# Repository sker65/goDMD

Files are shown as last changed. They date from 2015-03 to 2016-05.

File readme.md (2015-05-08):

# goDMD

Firmware for den pinguino micro zum bau einer goDmd Uhr.

Blog mit Anleitungen und vielen weiter führenden Hinweisen auf http://go-dmd.de/

# Setup der IDE

Als IDE kann Eclipse IDE genutzt werden. Siehe http://cogito-ergo-blog.de/blog/2015/02/25/eclipse-cdt-zur-pic-pic32-entwicklung-nutzen/

# Setup der Umgebung

Dieses Projekt nutzt einen chipKit core und einige Bibliotheken daraus. Um einen passende Core als libCore_api.a zum Linken zu haben, 
empfielt es sich dafür ebenfalls ein Eclipse CDT Projekt zu machen.
Auf dieses Projekt kann dann verwiesen werden.

## Libraries

Die Libraries die genutzt werden sind direkt aus dem Eclipse Workspace heraus verlinkt und 
zeigen auf die UECIDE Installation im home verzeichnis, wo der chipKit core Quellcode abgelegt ist.
Hier sind ggf. die Pfade in den Eclipse-Links anzupassen.

## IRremote Library
Die IR Remote Library wurde für den _Empfang_ an die PIC Umgebung angepasst und das Recorden
des IR Eingangs im Interrput angepasst.

Was nicht geht ist das Senden von IR Command. Die betreffen Stellen, die die PWM Signale 
erzeugen müssen noch von Arduino nach PIC portiert werden.

# SD Library
Diese Library ist eine projekt lokale Kopie der Lib aus dem ChipKIT core mit kleineren 
Anpassungen, damit sie aus dem pinguino micro ohne Probleme läuft.

Änderungen:
SD:
- seekCur eingefügt.

Sd2Card:
- setTranfersize to 8 bit
- setSpeed to 10000000UL (instead of 20000000UL) faster speed does not work

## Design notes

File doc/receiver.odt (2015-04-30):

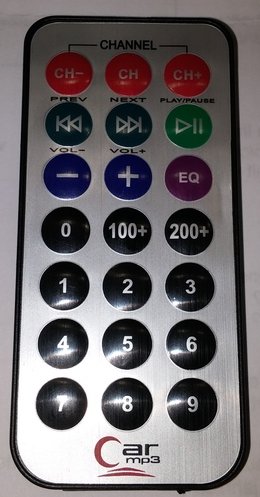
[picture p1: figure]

# Codes für die Fernbedienung der goDMD

Beschreibung | Code
CH- (rot) | 0xe318261b
CH (rot) | 0x00511dbb
CH+ (rot) | 0xee886d7f
Prev (grün) | 0x52a3d41f
Next (grün) | 0xd7e84b1b
Play (grün) | 0x20fe4dbb
- (blau) | 0xf076c13b
+ (blau) | 0xa3c8eddb
EQ (lila) | 0xe5cfbd7f
0 | 0xc101e57b
100+ | 0x97483bfb
200+ | 0xf0c41643
1 | 0x9716be3f
2 | 0x3d9ae3f7
3 | 0x6182021b
4 | 0x8c22657b
5 | 0x488f3cbb
6 | 0x0449e79f
7 | 0x32c6fdf7
8 | 0x1bc0157b
9 | 0x3ec3fc1b

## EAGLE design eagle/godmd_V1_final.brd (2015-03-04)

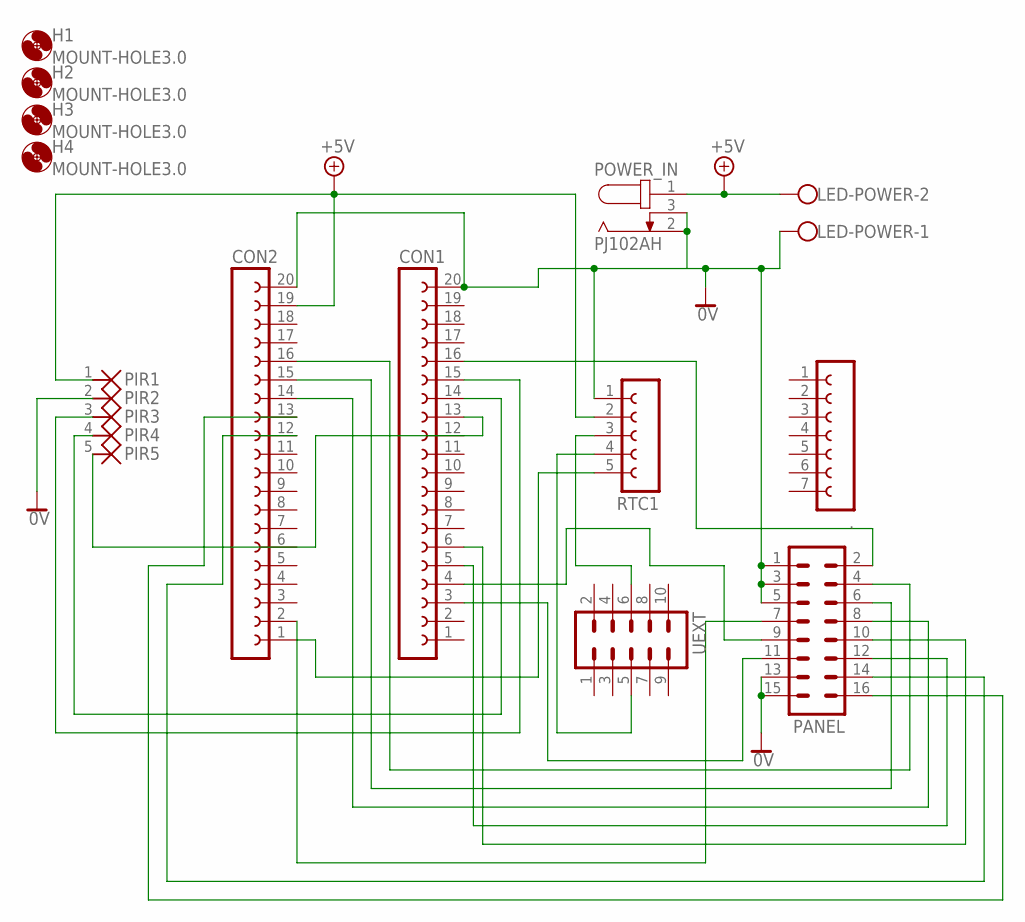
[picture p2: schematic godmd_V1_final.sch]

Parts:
.: FE07-1; FE07
CON1, CON2: FE20-1; FE20
H1, H2, H3, H4: MOUNT-HOLE3.0; 3,0
LED-POWER: W237-102
PANEL: MA08-2
PIR: PS25_5
POWER_IN: PJ102AH; PJ102
RTC1: FE05-1
UEXT: ML10

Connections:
0V: CON1.20, CON2.20, LED-POWER.1, PANEL.1, PANEL.3, PANEL.5, PANEL.13, PANEL.15, PIR.2, POWER_IN.2 (1), POWER_IN.3 (2), RTC1.1
+5V: CON2.19, LED-POWER.2, PIR.1, POWER_IN.1 (3), RTC1.2
A: CON1.16, PANEL.2
B: CON2.16, PANEL.4
C: CON2.15, PANEL.6
CLK: CON2.13, PANEL.16
D: CON2.14, PANEL.8
GD1: CON1.6, PANEL.10
GD2: CON1.5, PANEL.12
IRREC: CON1.14, PIR.4
LAT: CON2.12, PANEL.14
unnamed: RTC1.3, UEXT.6
unnamed: RTC1.4, UEXT.5
unnamed: CON2.1, RTC1.5
unnamed: CON2.2, PANEL.7
PIR-AUX: CON1.13, PIR.5
PIRDATA: CON1.15, PIR.3
RD1: CON1.4, PANEL.9
RD2: CON1.3, PANEL.11

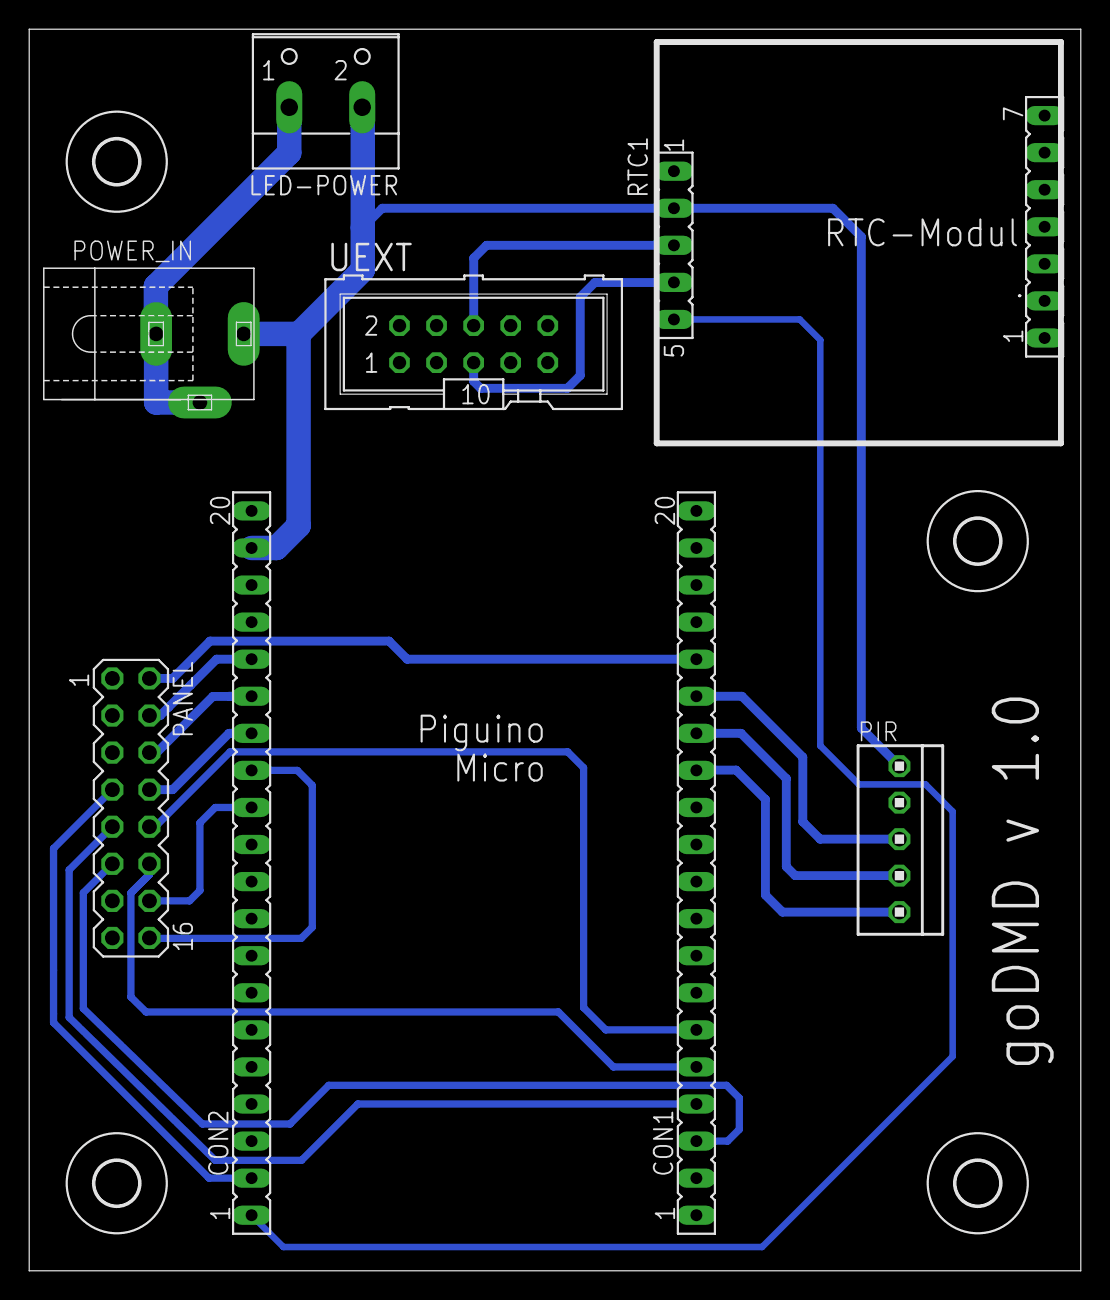
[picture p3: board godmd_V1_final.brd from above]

Board: 2 copper layers, 72.1 x 85.1 mm, 13 parts (0 on the bottom side), 19 nets.

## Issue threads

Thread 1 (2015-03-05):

farbwechsel in main loop

sker65, 2015-03-05:
Das Menü bietet einen Farbwechsel für Animation und Uhr an. Ist aber noch nicht implementiert

sker65, 2015-05-08:
ist nun verfügbar der Wechsel ist zufällig alle 60 sec

Closed 2015-05-08.

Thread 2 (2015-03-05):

helligkeits regelung LED

sker65, 2015-03-05:
Overall helligkeits steuerung ist noch nicht implementiert
an ende des interrupts, müssen die LED aus bleiben für einen Anteil der
Zeit die eigentlich gesetzt ist und zwar jedes zweite mal.

sker65, 2015-05-08:
einfach mit den Abtastzeiten realisiert

Closed 2015-05-08.

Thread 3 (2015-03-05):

kleiner Font für Uhr unterstützen

sker65, 2015-03-05:
die Uhr soll bei laufender Animation auch mit alternativem kleinen Font gezeigt werden.

Font wird bereits geladen, aber anzeige geht noch nicht.

sker65, 2015-03-06:
beim Anzeigen des kleinen Fonts muss darauf geachtet werden, dass die Bits passend zum yoffset verschachtelt werden. Evtl. ist es besser den kleinen Font daher nicht schon vorher zur transformieren

sker65, 2015-03-10:
umstellung auf regular bit planes, kleiner font geht

Closed 2015-03-11.

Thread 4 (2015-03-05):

EEPROM mit SDCard simulieren

sker65, 2015-03-05:
da der PIC kein EEPROM hat und das flashen nicht korrekt funktioniert, soll einfach ein SD File geschrieben werden was die Einstellungen speichert.

Ist implementiert, funktioniert aber irgendwie nicht korrekt

sker65, 2015-03-05:
funktioniert jetzt

Closed 2015-03-05.

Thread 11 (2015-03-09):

FSK Tag supporten

sker65, 2015-03-09:
geschrieben / gelesen wird das im file format bereits, aber noch nicht danach gefiltert.
Um filtern zu können, muss noch eine Einstellung ins Menü mit der man die Altersgrenze festlegt

sker65, 2015-03-11:
Menü Eintrag ist da, Filter klappt

Closed 2015-03-11.

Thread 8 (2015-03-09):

Zwischen den Sync-Punkte zur RTC geht die Uhr nach

sker65, 2015-03-09:
Zwischen den Sync-Punkte zur RTC geht die Uhr nach. Passt irgendwie nicht

sker65, 2015-03-16:
sollte weg sein, jetzt wird als aktuelle bezugspunkt immer millis() gerufen

sker65, 2015-05-02:
das zählen der millis ist tatsächlich ungenau, wegen der vielen Zeit die die CPU im Interrupt verbringt.
Lösung bislang: es wird öfter mit der RTC sychronisiert

Closed 2015-05-02.

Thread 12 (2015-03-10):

Ablauf der DMD Animation mit zufälliger Reihenfolge

sker65, 2015-03-10:
Um den Ablauf zufällig zu machen, sollte das File einmal komplett indiziert sein, d.h. der Anfang der Animation muss bekannt sein.

Entweder der Compiler erzeugt so ein Verzeichnis oder es wird zur Laufzeit aufgebaut.

sker65, 2015-03-16:
done

Closed 2015-03-16.

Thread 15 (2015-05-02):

grosse Schrift geht nicht mit Maske (oben drüber)

sker65, 2015-05-02:
wird aktuell nicht genutzt. sollte umgestellt werden, in der Form, dass die die Maske in den Buffer schreibt (Vielleicht ist der Buffer einfach ein weiterer Font)

sker65, 2015-05-08:
da gibts noch effekte, muss ich untersuchen

sker65, 2015-08-02:
fixed in 1.03

Closed 2015-08-02.

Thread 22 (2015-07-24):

Anzeige der Temperatur häufiger

sker65, 2015-07-24:
EInstellbar machen

juergen-schuch, 2015-08-02:
Auch die Anzeigedauer änderbar?

sker65, 2015-08-02:
- fix with 1.02

Closed 2015-08-02.

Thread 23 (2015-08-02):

Clock is not settable

juergen-schuch, 2015-08-02:
Not possible to set the time
after adjust time and date with remote control or the button
the displayed time starts always wit 17:30
Setting for i.e. time display hh:mm / hh:mm:ss works
firmware is newest : goDMD-1.01.hex
date is 29.04.43 although in setting menue the year is correct: 2015

sker65, 2015-08-02:
Possible hardware error. RTC adjusts are written to the rtc modul directly when menu is closed.
in this sense time / date adjusts are different from other options, which are written to file.

Closed 2015-08-02.

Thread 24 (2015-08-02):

Pixel für FB Anzeige per Menü deaktiveren

master-of-chaos, 2015-08-02:
Anscheinend registriert der IR Empfänger auch Signale anderer Fernbedienungen .
Hier wäre es schön, wenn man die Signalisierung des Empfangs durch den linken obersten Pixel per Setting deaktivieren könnte,

sker65, 2015-08-02:
Wird in einem der nächsten Releases supported werden.

sker65, 2015-08-02:
fixed in 1.03

Closed 2015-08-02.

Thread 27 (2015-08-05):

Issues 1.05 - Switch from and to animations buggy

Spyke1975, 2015-08-05:
- before date appears clock is shown shortly
- if date is shown, after finishing animations date is shown shortly before clock appears
- temperature stays dark within animation

sker65, 2015-08-06:
temp -> ani: clock.clear() seems to be missing. Temp is displayed in the back.
insert clock while ani, reset clock mode always to clock, regardless if it was date / temp

Closed 2015-08-13.

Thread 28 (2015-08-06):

Check IR-Codes in 1.05

sker65, 2015-08-06:
After updating ir codes and flashing my personal clock, absolutly no code is recognized any more.

Codes now look completely different, not sure if tested with Ralf remote, are there two different types of remotes?

sker65, 2015-08-07:
there is a dependency to the used hardware ir receiver. prototype board is other than series.

must be checked carfully, when doing a new series

Closed 2015-08-07.

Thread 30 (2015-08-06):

Create a menu to choose a temperatur offset

sker65, 2015-08-06:
As the tempature sensors are not very accurate, it should be possible to add / subtract an offset to the actual measured temperature

sker65, 2015-08-07:
- fixed in 1.06

Closed 2015-08-07.

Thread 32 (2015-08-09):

Handle overflow of millis()

sker65, 2015-08-09:
millis will overflow after 49 day, make sure clock is running well on overflow.

suggestions:
- register / reset all milli storing var in a way that they can be reseted / adjusted
- switch to another time var with 0.1 sec resolution to get a 4900 day overflow period.
-> this can be done by register a timer0 callback in chipkit

Closed 2015-10-05.

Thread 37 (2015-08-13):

Uhr bleibt nach einiger Zeit dunkel

sker65, 2015-08-13:
_From @eliottk on August 8, 2015 10:52_

Meine Uhr hat das Problem, dass sie nachdem sie sich ausgeschalten hat, da sich niemand im Raum befand und zappelte, sich hin und wieder nicht mehr einschaltet. Das ganze geht ein paar mal gut und dann bleibt sie dunkel. Ich muss dann einen Reset machen und dann geht sie wieder.

_Copied from original issue: sker65/go-dmd-clock#8_

sker65, 2015-08-13:
Leider das falsche Projekt

eliottk, 2015-08-15:
Hi,

jetzt kenne ich mich nicht mehr aus, wieso das falsche Projekt? Es geht hier doch um die Probleme mit der GO-DMD Uhr von dir oder?

lg.
Erich

mdillmann, 2015-08-15:
Erich, Du hattest den Bug report im Projekt der Werkzeuge (go-dmd-clock) geöffnet. Das Projekt für die Firmware ist das goDMD.
Stefan hat das rüberkopiert.

Zugegeben, Stefan hat das etwas unglücklich benannt ...

VG,
-Markus

eliottk, 2015-08-16:
Hi,

okay danke.

Folgende Einstellungen habe ich bei meiner Uhr, evt. ist ja ein Software Problem:

FW: 1.05
Helligkeit: 4
Zeit Mode: H:M
Dauer Zeit Anzeige: 5
Dauer Dat Anz: 2
Farbe-Ani: wechsel
Farbe-Uhr: wechsel
Dauer Temp Anz: 4
PIR Mode: switchoff
FSK: 18
Uhr Blink: an
Uhr 12/24: 24
Ani Reihenfolge: zufällig
Schrift: 0
LED Indicator: an
PIR Hold Time: 1

Die Uhr geht nach ca. 21 min. aus und kommt nicht mehr retour. Erst nach eine, reset (Knopf oder Stroemkabel) funktioniert sie wieder für 21 min.

lg.
Erich

sker65, 2015-08-16:
Hi Erich, bitte teste mal ohne den FSK filter. Der war schon mal Ursache
für ein Problem. Ist nur so ein Gefühl, eigentlich sehen die Einstellungen
OK aus.
Gruss Steve

eliottk <notifications@github.com> schrieb am So., 16. Aug. 2015 15:03:

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

eliottk, 2015-08-16:
Hi,

auf was soll das FSK stellen, ich kann da ja nur 6, 12, 18 auswählen. OFF gibt es da nicht.

lg.
Erich

sker65, 2015-08-16:
Na probiere halt mal irgendwas anderes es sind ja nur vier stufen.
Gruss Steve

eliottk <notifications@github.com> schrieb am So., 16. Aug. 2015 16:21:

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

eliottk, 2015-08-17:
Hi,

der Filter war es nicht, es scheint die foo.ani Datei zu sein die den Fehler verursacht. Ich habe heute mal eine neue gemacht mit nur 3-4 Animationen und seither läuft die Uhr.

@sker65
Ich sende dir einen Dorpbox Link per Mail mit der foo.ani mit der sie nicht funktioniert hat. evt. kanst du den Fehler finden.

lg.
Erich

sker65, 2015-08-17:
Ok, gut Erich, dass du den Fehler eingrenzen konntest. Wichtig wäre noch zu wissen, welche Firmware Version du verwendest.

sker65, 2015-08-17:
sorry ich habs grad gesehen, es ist die 1.05

eliottk, 2015-08-17:
Ok, der Link zur der verwendeten foo.ani ist auch raus an dich.

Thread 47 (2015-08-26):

Speed up serial communication with ESP to 112500 baud

sker65, 2015-08-26:
in preparation of file transfer the speed of the comm link to ESP must be faster.

as the esp is not reseted, when pic restarts, we need to sync baud rates, regardless what the uart of the esp is set, like this: try 9600, expect crap or CR/LF, try 112500 expect CR/LF

to not delay boot time, we maybe post pone the whole detection as update task.

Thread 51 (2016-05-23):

frame replacement shows error

sker65, 2016-05-23:
see http://vpuniverse.com/forums/topic/2268-pin2dmd-editor/?p=29321

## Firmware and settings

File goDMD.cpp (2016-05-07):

/*
 * go DMD main.
 *
 *  Created on: 08.02.2015
 *      Author: sr
 *      (c) 2015 by Stefan Rinke
 */

#include <IRremote.h>
#include <OneWire.h>
#include <SD.h>
#include <RTClib.h>
#include <DallasTemperature.h>

#include "NtpCallbackHandler.h"
#include "LEDMatrixPanel.h"
#include "Clock.h"
#include "Animation.h"
#include "Menu.h"
#include "PirHandler.h"
#include "NodeCallbackHandler.h"
#include "debug.h"
#include "version.h"
#include <malloc.h>
#include "macros.h"
#include "utility/TimeUtil.h"
#include "DHT.h"

#define DS18B20_PIN CON2_1

#define CLK CON2_13
#define OE CON2_2
#define LAT CON2_12 // schwarz 
#define A CON1_16 // RB0
#define B CON2_16 // RB1
#define C CON2_15 // RB2
#define D CON2_14 // RB3

#define WIDTH 128
#define HEIGHT 32
#define PLANES 16
#define COLORCHANNELS 2

#define INTERNAL_SD_SELECT 51

#define RECV_PIN CON1_14
#define PIR_PIN CON1_15
#define DHT_PIN CON1_16

DHT dht(DHT_PIN);

LEDMatrixPanel panel( A,B,C,D, CLK, LAT, OE, WIDTH, HEIGHT, PLANES,
		COLORCHANNELS, false);

OneWire oneWire(DS18B20_PIN);          // OneWire Referenz setzen
DallasTemperature sensor(&oneWire);   // DS18B20 initialisieren
RTC_DS1307 rtc;

Clock clock(panel, rtc, &SD, &sensor, &dht);
Animation animation(SD, panel, clock);

// set time zone to 1 as default for germany
NtpCallbackHandler ntpCallbackHandler(&clock, 1);
NodeCallbackHandler nodeCallbackHandler(&panel);

NodeMcu node(&ntpCallbackHandler,&nodeCallbackHandler);

Menu menu(&panel, &clock, &SD, &node);

IRrecv irrecv(RECV_PIN);
decode_results results;

PirHandler pir(PIR_PIN);

long nextPixel = 0;
int x = 0;
int y = 0;
bool on=false;


extern "C" char* sbrk(int incr);
int getFreeRam() {
  char top;
  return &top - reinterpret_cast<char*>(sbrk(0));
}

// define a char out hook for printf
extern "C"
{
  void _mon_putc(char s)
  {
   Serial.write(s);
  }
}

void waitBut() {
	panel.println("press button");
	while(digitalRead(PIN_BTN1)==LOW);
	while(digitalRead(PIN_BTN1)==HIGH);
}

#include "ir-codes.h"

void selftest() {
	panel.println("SELFTEST");
	panel.println(VERSION);
	waitBut();
	panel.println("PANELTEST");
	int b = 0;
	boolean run = true;
	boolean seenHigh = false;
	int col = 0;
	int br = 3;
	panel.setAnimationColor(col);
	panel.drawRect(0,0,128,32,br++);
	while( run) {
		if( irrecv.decode(&results) ) {
			if( results.value == BUT_7 && b>0 ) {
				b--;
			}
			if( results.value == BUT_8 && b<10 ) {
				b++;
			}
			if( results.value == BUT_9 ) run = false;
			if( results.value == BUT_1 ) {
				DPRINTF("draw col=%d br=%d\n",col,br);
				panel.setAnimationColor(col);
				panel.drawRect(0,0,128,32,br++);
				if( br >= 4) { //  4
					br = 1;
					col++;
					if( col == 3) col = 0;
				}
			}
			panel.setBrightness(b);
			DPRINTF("set Brightness to %d\n",b);
			irrecv.resume();
		}
		if( digitalRead(PIN_BTN1)==HIGH ) seenHigh = true;
		if( seenHigh && digitalRead(PIN_BTN1)==LOW ) run=false;
	}

	// one pager
	run = true;
	seenHigh = false;
	long update = 0;
	uint32_t lastIr = 0;
	panel.clear();
	while(run) {
		uint32_t now = millis();
		// just hand over
		if( Serial.available() ) {
			int in = Serial.read();
			Serial1.write(in);
		}
		if( Serial1.available()) {
			int out = Serial1.read();
			Serial.write(out);
		}
		if( SAVECMP(now, update) ) {
			update = now+1000;
			if( pir.actual() ) panel.writeText("PIR: true   ",0,0,12);
			else panel.writeText("PIR: false  ",0,0,12);
			char buf[16];
			sprintf(buf,"0x%08x",lastIr);
			panel.writeText(buf,0,8,10);
			sensor.requestTemperatures();
			float actTemp = sensor.getTempCByIndex(0);
			sprintf(buf, "%03.1f *C",actTemp);
			panel.writeText(buf,0,16,7);
			DateTime n = rtc.now();
			sprintf(buf,"%02d:%02d:%02d %02d%02d%02d",
					n.hour(),n.minute(),n.second(),
					n.day(),n.month(),n.year()%1000);
			panel.writeText(buf,0,24,15);
		}
		if( irrecv.decode(&results) ) {
			lastIr = results.value;
			DPRINTF("ircode received %04x\n",lastIr);
			irrecv.resume();
			if( results.value == BUT_9 ) run = false;
		}
		if( digitalRead(PIN_BTN1)==HIGH ) seenHigh = true;
		if( seenHigh && digitalRead(PIN_BTN1)==LOW ) run=false;
	}
	run = true;
	seenHigh = false;
	panel.clear();
	node.start();
	node.setEnableBackgroundCmds(false);
	while(run) {
		uint32_t now = millis();
		node.update(now);
		if( SAVECMP(now,update) ) {
			update = now+1000;
			if( node.isNodeMcuDetected()) {
				panel.writeText("wifi ext active",0,0,15);
				char* ip = node.syncRequestIp();
				char buf[16];
				sprintf(buf, "%-16s",ip);
				panel.writeText(buf,0,8,16);
			} else {
				panel.writeText("no wifi ext.",0,0,12);
			}


		}
		if( digitalRead(PIN_BTN1)==HIGH ) seenHigh = true;
		if( seenHigh && digitalRead(PIN_BTN1)==LOW ) run=false;
	}
	panel.println("press but to cont");
	while( true ){
		panel.setAnimationColor(col);
		panel.drawRect(0,0,128,32,br++);
		if( br == 4) { //  4
			br = 1;
			col++;
			if( col == 3) col = 0;
		}
		delay(700);
		if( digitalRead(PIN_BTN1)==FALSE ) break;
	}
	panel.println("press but to cont");
	waitBut();
	//panel test
	panel.println("IR TEST");
	panel.println("press buttons");
	// loop to receive
	if( irrecv.decode(&results) ) {
		char buf[12];
		sprintf(buf,"0x%08x",results.value);
		panel.println(buf);
		irrecv.resume();
	}


}


void setup() {
	Serial.begin(9600);
#ifdef _DxEBUG
	for( int i =0; i<5;i++) {
		DPRINTF("wait %lu \n", millis());
		delay(1000);
	}
#endif
	DPRINTF2("calling panel begin\n");
	panel.begin();

	panel.setAnimationColor(1);
	panel.setTimeColor(1);
	DPRINTF2("\n");

	node.begin();



	// start ir receiver
	irrecv.enableIRIn();

	panel.println(VERSION);

	DPRINTF2("calling wire begin\n");
	panel.println("start wire ..");
	Wire.begin();
	DPRINTF2("calling rtc begin\n");
	panel.println("start rtc ..");
	rtc.begin();
	
	DPRINTF2("calling sd card begin\n");
	panel.println("start sd card ..");

	if( !SD.begin(INTERNAL_SD_SELECT) ){
	pinMode(INTERNAL_SD_SELECT, OUTPUT);
		DPRINTF2("sd card begin failed\n");
		panel.println("sd card failed");
		selftest();
	} else {
		DPRINTF2("sd card begin success\n");
		delay(500);
		panel.println("boot ok!");
		panel.println("(c)2015 by Steve");
	}

	if( !clock.begin() ) {
		panel.println("init clock fail");
		panel.println("font not found");
	}

	if( !animation.begin() ) {
		panel.println("init anis fail");
		panel.println("*.ani not found");
	}

	uint32_t pclock = getPeripheralClock();
	DPRINTF("system running with periphal clock : %ld\n",pclock);

	sensor.begin();
	DPRINTF("sensors found: %d\n",sensor.getDeviceCount());

//	DPRINTF("Running at: %d\n", System.get());

	if(digitalRead(PIN_BTN1)==FALSE) {
		selftest();
	}

	panel.clear();
	panel.clearTime();

	//pinMode(PIN_LED2,OUTPUT);

	//rtc.adjust(DateTime(__DATE__, __TIME__));
}

int clockShowTime = 2000; // millis to show clock
// viewing mode (with date or not)
int dateMode = 0;
int tempMode = 0;

// TODO no global function this way
void reloadConfig() {
	panel.setAnimationColor(menu.getOption(SET_COLOR_ANI));
	panel.setTimeColor(menu.getOption(SET_COLOR_CLOCK));
	panel.setBrightness(menu.getOption(SET_BRIGHTNESS));
	DPRINTF("panel.setBrightness: %d\n", menu.getOption(SET_BRIGHTNESS));

	clock.setMode(menu.getOption(SET_TIME_MODE)==1?Clock::TIMESEC:Clock::TIME);
	DPRINTF("set time mode: %d\n", menu.getOption(SET_TIME_MODE));

	clockShowTime = 1500 * (menu.getOption(SET_TIME_DURATION)+1);
	dateMode = menu.getOption(SET_DATE_MODE);
	tempMode = menu.getOption(SET_TEMP_MODE);
	animation.setFskMode(menu.getOption(FSK_MODE));
	animation.setRandomOrder(menu.getOption(ANIORDER_MODE)==1);
	clock.setHour24(menu.getOption(H2412_MODE)==MODE_24H);
	clock.setBlinkingTick(menu.getOption(BLINK_MODE)==BLINK_ON);
	clock.requestFont(menu.getOption(CURRENT_FONT));
	pir.setDelay((30+15*menu.getOption(PIR_HOLDTIME))*1000);
	animation.setShowName(menu.getOption(DISPLAY_ANINAME)==0);
	clock.setTempOffset(menu.getOption(TEMP_OFFSET)-7);
}

void testScreen() {
	for( int col = 0; col<16; col++) {
		panel.drawRect(col*8,0,8,32,col);
	}
	while(true);
}

// push main loop behaviour to class

// states
enum State { showTime, showDate, showAni, showMenu, freeze,
	pirNobodyThere, showTemp, showHumi
};

void loop() {
	uint32_t now = millis();

	State state = showTime;

	DHT::ReturnCode rc = dht.readDHT();
	bool dhtPresent = ( rc == DHT::DHT_OK );

	//testScreen();

	menu.loadOptions();
	reloadConfig();

	DPRINTF("free ram %d\n", getFreeRam());

	uint32_t ledInterval = 3000;

	uint32_t switchToAni = now + clockShowTime;

	uint32_t nextColorChange = 0;

	int stateCycle = 0;
	int dateTemp = 0;

	int dstCheck = 0;

	/*int next = millis();

	while( true ) {
		long now = millis();
		if( now > next ) {
			next = now + 5000;
			Serial1.println("=node.info()");
		}
		// just hand over
		if( Serial.available() ) {
			int in = Serial.read();
			Serial1.write(in);
		}
		if( Serial1.available()) {
			int out = Serial1.read();
			Serial.write(out);
		}
	}*/

	node.start();

/*	int t = 0;
	while(t++ < 20) {
		long now = millis();
		node.update(now);
		delay(100);
	}
	DPRINTF("ip: %s\n",node.getIp());
	while(t++ < 20) {
		long now = millis();
		node.update(now);
		delay(100);
	}
	Result* r = node.getApList();
	while( r != NULL ) {
		DPRINTF("AP: %s\n", r->line);
		r = r->next;
	}*/
	bool hasNtpRequested = false;
	bool wifipresetRequested = false;

	TimeUtil timeUtil;
	clock.update(millis());
	timeUtil.setUTCtime(clock.getUnixTime());
	bool actDst = timeUtil.isDaylightSaving();
	bool toggleHumi = false;

	while(true) {
		uint32_t now = millis();

		node.update(now);
		if( now > 1000 && node.isNodeMcuDetected() && menu.hasWifiPreset() && wifipresetRequested == false) {
			wifipresetRequested = true;
			DPRINTF("wifi preset ssid: '%s'\n",menu.getPreset_ssid());
			DPRINTF("wifi preset pw: '%s'\n",menu.getPreset_pw());
			node.configAp( menu.getPreset_ssid(), menu.getPreset_pw());
		}

		if( now > 40000 && node.isNodeMcuDetected() && hasNtpRequested==false ) {
			hasNtpRequested = true;
			node.requestNtpSync(now);
		}

		if( Serial.available() ) {
			String ps = Serial.readStringUntil('\n');
			const char* p = ps.c_str();
			DPRINTF("received string: '%s'\n",p);
			// date +SETTIME%s > /dev/ttyACM0
			// SETTIME<seconds since 1970 utc>
			if( strncmp(p,"SETTIME",7)==0) {
				p += 7;
				long unixtime = 0;
				while( *p != 0) {
					unixtime *= 10;
					if( *p >= '0' && *p <= '9') {
						unixtime += *p -'0';
					}
					p++;
				}
				// simple hack to adjust tz CEST +2 hours
				unixtime += 60*60*2;
				DateTime dt(unixtime);
				DPRINTF("setting rtc clock to: %ld \n", unixtime);
				clock.adjust(&dt);
			}
		} // read from serial

		// handle IR receiver
		if( irrecv.decode(&results) ) {
			menu.notifyEvent(results.value);
			irrecv.resume();
		}
		
		// show with blinking led ISR is running
		// cannot be switched on as it interferes with card reader
		if( panel.getISRCalls() > ledInterval ) {
			panel.resetISRCalls();
			on = !on;
			//digitalWrite(PIN_LED2,on);
			ledInterval = on ? 10000:10000;
			//DPRINTF("free ram %d\n", getFreeRam());
		}

		pir.update(now);
		clock.update(now);
		menu.update(now);

		if( menu.isActive() ) {
			clock.off();
			state = showMenu;
		}


		// do an dst check every minute, regardless
		if( SAVECMP(now, dstCheck)) {
			dstCheck = now + 60000;
			uint32_t unixTime = clock.getUnixTime();
			timeUtil.setUTCtime(unixTime);
			bool dstNew = timeUtil.isDaylightSaving();
			if( dstNew != actDst ) {
				// make dst adjust
				if( dstNew ) {
					// switch to summer time
					DPRINTF2("switching to summer time");
					DateTime dt(unixTime + 3600);
					clock.adjust(&dt);
				} else {
					// switch back to winter time
					DPRINTF2("switching to winter time");
					DateTime dt(unixTime - 3600);
					clock.adjust(&dt);
				}
				actDst = dstNew;
			}
		}

		// ani -> time -> ani
		// or ani -> date -> ( ani -> time -> ) 5x

		switch( state ) {
		case showTime:
			clock.on();
			if( SAVECMP( now , switchToAni) ) {
				DPRINTF("free ram %d\n", getFreeRam());
				if(pir.somebodyHere()) {
					state = showAni;
					clock.off();
					panel.setBrightness(menu.getOption(SET_BRIGHTNESS));
				} else {
					switch( menu.getOption(SET_PIR_MODE) ) {
					case PIR_DIM:
						panel.setBrightness(1);
						// run through is intended
					case PIR_INACTIVE:
						state = showAni;
						clock.off();
						break;
					case PIR_NOANI:
						switchToAni = now + clockShowTime;
						// TODO check date show
						// define transitions as methods
						break;
					case PIR_SWITCHOFF:
						clock.off();
						panel.clear();
						state = pirNobodyThere;
						break;
					}
				}
			}
			clock.update(now);
			break;

		case showTemp:
			clock.setMode(Clock::TEMP);
			clock.on();
			if( SAVECMP( now , switchToAni ) ) {
				state = showAni;
				clock.off();
			}
			clock.update(now);
			break;

		case showHumi:
			clock.setMode(Clock::HUMI);
			clock.on();
			if( SAVECMP( now , switchToAni ) ) {
				state = showAni;
				clock.off();
			}
			clock.update(now);
			break;

		case showDate:
			clock.setMode(Clock::DATE);
			clock.on();
			if( SAVECMP( now , switchToAni ) ) {
				state = showAni;
				clock.off();
			}
			clock.update(now);
			break;

		case showAni:
			if( animation.update(now) ) { // true means ani finished

				if( stateCycle++ > 5 ) { // every five times
					stateCycle = 0;
					dateTemp++;
					// check want to show next temp ot date or simply time
					if( tempMode>0 && dateTemp % 3 == 0 ) {
						toggleHumi = ~toggleHumi;
						if( toggleHumi && dhtPresent ) {
							state=showHumi;
						} else {
							state=showTemp;
						}
						switchToAni = now + 3000 + tempMode * 1500;
					} else {
						if( dateMode > 0 ) {
							state = showDate;
							clock.setMode(Clock::DATE);
							switchToAni = now + 3000 + dateMode * 1500;
						}
					}
				} else {
					switchToAni = now + clockShowTime; // millis to show clock
					state = showTime;
					clock.setMode(menu.getOption(SET_TIME_MODE)==1?Clock::TIMESEC:Clock::TIME);
				}

				// check color change
				if( SAVECMP( now , nextColorChange ) ) {
					nextColorChange = now + 60000;
					if( menu.getOption(SET_COLOR_ANI)==COLOR_CHANGE ) {
						panel.setAnimationColor(random(3));
					}
					if( menu.getOption(SET_COLOR_CLOCK)==COLOR_CHANGE ) {
						panel.setTimeColor(random(3));
					}
				}

			}
			break;

		case showMenu:
			if( !menu.isActive()) {
				// menu is finish / clock is set, but reconfige ani / panel
				reloadConfig();
				state = showTime;
			}
			break;

		case pirNobodyThere:
			ledInterval = 6000;
			if( pir.somebodyHere()) {
				ledInterval = 3000;
				switchToAni = now + clockShowTime; // millis to show clock
				state = showTime;
			}
			break;
		case freeze:

			break;
		}
		
	}
}

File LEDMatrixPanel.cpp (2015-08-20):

/*
 * LEDMatrixPanel.cpp
 *
 *  Created on: 29.01.2015
 *      Author: sr
 */

#include "LEDMatrixPanel.h"
#include "debug.h"

// use this to control the color resolution per pixel per color channel
#define bitsPerPixel 2
#define clockPlane 2

#define LEDS_ACTIVE_HIGH

#if defined(__PIC32MX__) 

#include <p32xxxx.h>    /* this gives all the CPU/hardware definitions */
#include <plib.h>       /* this gives the i/o definitions */

#define DATAPORT LATE
//#define DATADIR  TRISE

//#define SCLKPORT LATD

#define R1_PIN CON1_4
#define R2_PIN CON1_3
#define G1_PIN CON1_5
#define G2_PIN CON1_6
#endif

// A full PORT register is required for the data lines, though only the
// top 6 output bits are used.  For performance reasons, the port # cannot
// be changed via library calls, only by changing constants in the library.
// For similar reasons, the clock pin is only semi-configurable...it can
// be specified as any pin within a specific PORT register stated below.

#if defined(__AVR_ATmega1280__) || defined(__AVR_ATmega2560__)
// Arduino Mega is now tested and confirmed, with the following caveats:
// Because digital pins 2-7 don't map to a contiguous port register,
// the Mega requires connecting the matrix data lines to different pins.
// Digital pins 24-29 are used for the data interface, and 22 & 23 are
// unavailable for other outputs because the software needs to write to
// the full PORTA register for speed.  Clock may be any pin on PORTB --
// on the Mega, this CAN'T be pins 8 or 9 (these are on PORTH), thus the
// wiring will need to be slightly different than the tutorial's
// explanation on the Uno, etc.  Pins 10-13 are all fair game for the
// clock, as are pins 50-53.
// port C is PIN 37 - 30 / PC0 - PC7
#define DATAPORT PORTC
#define DATADIR  DDRC

#define SCLKPORT PORTB

#define R1_PIN 30
#define R2_PIN 31
#define G1_PIN 32
#define G2_PIN 33


#elif defined(__AVR_ATmega32U4__)
// Arduino Leonardo: this is vestigial code an unlikely to ever be
// finished -- DO NOT USE!!!  Unlike the Uno, digital pins 2-7 do NOT
// map to a contiguous port register, dashing our hopes for compatible
// wiring.  Making this work would require significant changes both to
// the bit-shifting code in the library, and how this board is wired to
// the LED matrix.  Bummer.
#define DATAPORT PORTD
#define DATADIR  DDRD
#define SCLKPORT PORTB
#else
// Ports for "standard" boards (Arduino Uno, Duemilanove, etc.)
//#define DATAPORT PORTD
#define DATADIR  DDRD
#define SCLKPORT PORTB
#endif

static LEDMatrixPanel *activePanel = NULL;

LEDMatrixPanel::LEDMatrixPanel(uint8_t a, uint8_t b, uint8_t c, uint8_t d,
		uint8_t sclk, uint8_t latch, uint8_t oe, uint8_t width, uint8_t height,
		uint8_t planes, uint8_t colorChannels, bool useDoubleBuffering) {

	// Save pin numbers for use by begin() method later.
	_a = a;
	_b = b;
	_c = c;
	_d = d;
	_sclk = sclk;
	_latch = latch;
	_oe = oe;

	// Look up port registers and pin masks ahead of time,
	// avoids many slow digitalWrite() calls later.
	sclkport = portOutputRegister(digitalPinToPort(sclk));
	sclkpin = digitalPinToBitMask(sclk);
	//PORTClearBits(sclkport,sclkpin);
	
	latport = portOutputRegister(digitalPinToPort(latch));
	latpin = digitalPinToBitMask(latch);
	
	oeport = portOutputRegister(digitalPinToPort(oe));
	oepin = digitalPinToBitMask(oe);

	// address bits for rows
	addraport = portOutputRegister(digitalPinToPort(a));
	addrapin = digitalPinToBitMask(a);
	addrbport = portOutputRegister(digitalPinToPort(b));
	addrbpin = digitalPinToBitMask(b);
	addrcport = portOutputRegister(digitalPinToPort(c));
	addrcpin = digitalPinToBitMask(c);
	
	// only if four row address bits used
	addrdport = portOutputRegister(digitalPinToPort(d));
	addrdpin = digitalPinToBitMask(d);

	// meta data
	this->width = width;
	this->height = height;
	this->planes = planes;

	this->colorsChannels = colorChannels;

	// byte align width
	buffersize = width / 8 * height;

	nBuffers = bitsPerPixel * colorChannels + 1; // one for time buffer

	plane = 0;
	actBuffer = 0;
	timeColor = 0;
	aniColor = 0;
	timeBright = 0;
	brightness=0;

	// init text
	col = row = 0;
	// clear text buffer
	for(int c = 0; c <16; c++ ) {
		for(int r=0; r<4;r++) {
			textbuffer[r][c] = ' ';
		}
	}
	this->useDoubleBuffering = useDoubleBuffering;
	//scan = { 0, 15, 1, 14, 2, 13, 3, 12, 4, 11, 5, 10, 6, 9, 7, 8 };
	scan = { 0, 1,2,3,4,5,6,7,8,9,10,11,12,13,14,15};
}

LEDMatrixPanel::~LEDMatrixPanel() {
	// release memory
}


void LEDMatrixPanel::begin() {

	// double
    this->buffptr = (volatile uint8_t**) malloc(sizeof(*buffptr) * nBuffers * (useDoubleBuffering?2:1));

    for (int i = 0; i < nBuffers*(useDoubleBuffering?2:1); i++) {
		buffptr[i] = (volatile uint8_t*) malloc(buffersize);
		DPRINT("buffer %d at 0x%08x",i,(unsigned int)buffptr[i]);
		// delete buffer
		memset((void*)buffptr[i], 0x00, buffersize);
	}

	
	// Enable all comm & address pins as outputs, set default states:
	pinMode(_sclk, OUTPUT);
	//*sclkport &= ~sclkpin;  // Low
	digitalWrite(_sclk,LOW);

	pinMode(_latch, OUTPUT);
	//*latport &= ~latpin;   // Low
	digitalWrite(_latch,LOW);

	pinMode(_oe, OUTPUT);
	//*oeport |= oepin;     // High (disable output)
	digitalWrite(_oe,HIGH);

	plane = 0;
	pinMode(_a,OUTPUT);
	pinMode(_b,OUTPUT);
	pinMode(_c,OUTPUT);
	pinMode(_d,OUTPUT);

	selectPlane(0);

	// set data output bit to out
	//DATADIR = !(255 >> ( bitsPerPixel * colorsChannels));
	pinMode(R1_PIN,OUTPUT);
	pinMode(R2_PIN,OUTPUT);
	// green
	pinMode(G1_PIN,OUTPUT);
	pinMode(G2_PIN,OUTPUT);

	// maybe extend to simultaneously drive two colors at once (synchronous)
#ifdef __AVR__
	DATAPORT |= 0b11110000;
#endif
#ifdef __PIC32MX__
	DATAPORT |= 0b00001111;
#endif
	activePanel = this;

	setupTimer();

}

void LEDMatrixPanel::setupTimer() {

#ifdef __AVR__
	 // Set up Timer1 for interrupt:
	TCCR1A = _BV(WGM11); // Mode 14 (fast PWM), OC1A off
	TCCR1B = _BV(WGM13) | _BV(WGM12) | _BV(CS10); // Mode 14, no prescale
	ICR1 = 100;
	TIMSK1 |= _BV(TOIE1); // Enable Timer1 interrupt
	sei();
#endif
#ifdef __PIC32MX__
	OpenTimer1( T1_ON | T1_SOURCE_INT | T1_PS_1_8, 1000);
	// timer ein, internal source, prescaler 8 = 10 MHz, count 5000 => 2 Khz
	ConfigIntTimer1( T1_INT_ON | T1_INT_PRIOR_2); \
	INTEnableSystemMultiVectoredInt();
#endif
}

void LEDMatrixPanel::swap(bool vsync) {
	if( useDoubleBuffering ) {
		if( vsync ) this->swapPending = true;
		else swapInternal();
	}
}

void LEDMatrixPanel::swapInternal() {
	if( bufoffset == 0 ) bufoffset = nBuffers;
	else bufoffset = 0;
	swapPending = false;
}

void LEDMatrixPanel::selectPlane(uint8_t p) {
	LATB = (LATB & ~0x0F ) | p;
}

void LEDMatrixPanel::setBrightness(uint8_t p)
{
	if( p>=0 && p<= 6) {
		this->brightness = p;
	}
}



#define CYCLE_DURATION 1000

// this method will be called via the ISR 
void LEDMatrixPanel::updateScreen() {
	// called periodically to refresh led matrix

	isrCalls++;

	disableLEDs();
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

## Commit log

2015-03-03 - switch to eclipse
2015-03-04 - added font loading from file - added temperature display
2015-03-04 - used for debug printf output via serial
2015-03-04 - new debug macro for PRINTF - temp sensor linked with clock
2015-03-04 -old cfg from uecide
    [sketch.cfg]
2015-03-04 - added eagle files
    [godmd_V1_final.brd, godmd_V1_final.sch]
2015-03-05 - removed some unused (arduino) stuff
2015-03-05 - switched on DEBUG
2015-03-11 - added fsk filter - added x,y offset for small clock
2015-03-11 - fixed cycling - added handling for small clock - added fsk filter (not working until now)
2015-03-11 - added fsk filter
2015-03-11 - added temp mode for showing temperatur (sensor not working at the moment)
    [goDMD.cpp]
2015-03-11 - when skipping frames just read len of buf each time
2015-03-16 - fixed time offset bug - fixed check temperatur
2015-05-02 - fixed panel delete (just delete Animations buffer, not clock)
    [LEDMatrixPanel.cpp]
2015-05-05 - selftest on failure - try yellow led
    [goDMD.cpp]
2015-05-05 - use three state button
2015-05-06 - support for prop fonts
2015-05-08 - lower case
2015-05-08 - add positive led logik 0 = off, 1 = on
2015-05-08 - LEDS active high - birghtness controll
2015-08-02 - option for led indicator
2015-08-02 - bugfix clock on for date temp
    [goDMD.cpp]
2015-08-03 - adjusted ir receiver interrupt timer to 60Mhz sysclock
2015-08-18 - another rc with bugfixes
    [NodeMcu.cpp]
2015-08-20 - adjust timing, 100us sample rate
2015-08-20 - integrate node and request ntp once after switch on
2015-08-24 Fixes #41 - when in selftest, one can transparently use Serial to access the ESP
    [goDMD.cpp]
2015-08-26 - version - bugfix in menu cycle when in net menu - fixes #46
    [Menu.h]
2015-10-05 fixes #32 , overflow of millis
    [NodeMcu.cpp]
2016-02-18 - automatic dst check / switch
2016-03-29 - bugfix for dst check
    [goDMD.cpp]
